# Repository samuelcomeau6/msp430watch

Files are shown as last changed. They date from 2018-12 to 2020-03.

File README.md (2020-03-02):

# msp430watch

These are the source and design files for my MSP430 based wrist watch.

See https://hackaday.io/project/163005-msp430fr5994-based-wrist-watch for project write up and documentation.

This project was designed for me to personally learn more about electronics design and embedded software design. As such, there are guaranteed to be bugs, issues and things that can be improved. I recommend not taking any of my instructions or designs at face value. However, I do have a working device so I must of done something right.

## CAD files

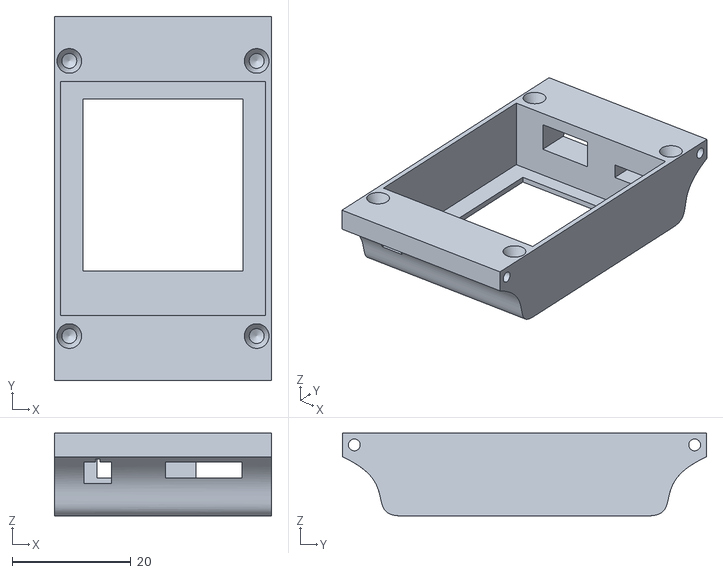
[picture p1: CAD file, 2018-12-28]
Case/body.stl
36.6 x 61.4 x 14.0

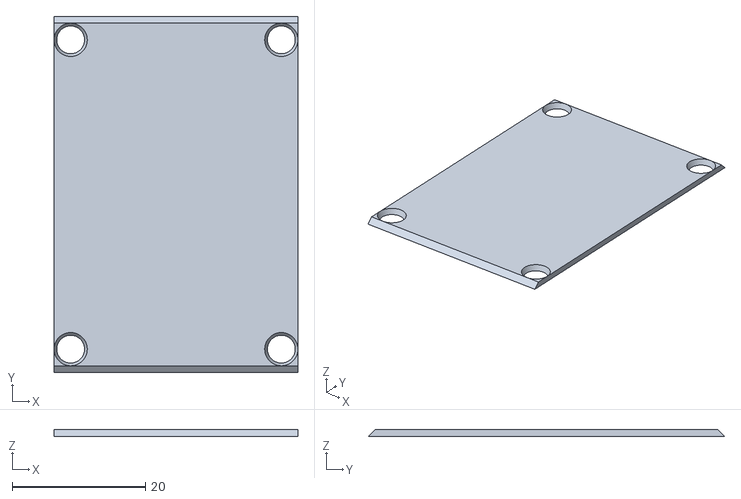
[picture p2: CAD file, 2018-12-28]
Case/backcover.stl
36.6 x 53.4 x 1.00

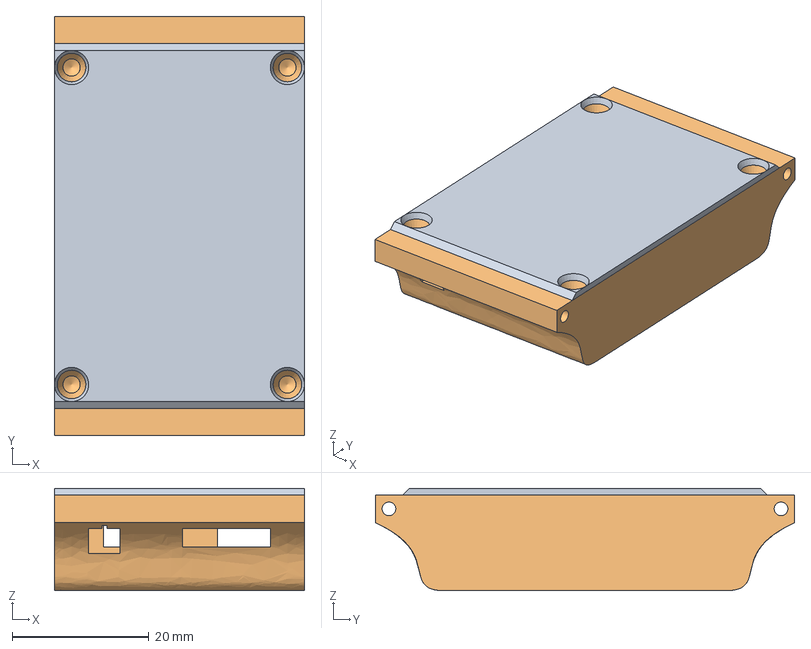
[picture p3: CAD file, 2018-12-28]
Case/watch body v4.step
36.6 x 61.4 x 15.0 mm

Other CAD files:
Case/watch body v4.f3d
Case/watch body v4.iges

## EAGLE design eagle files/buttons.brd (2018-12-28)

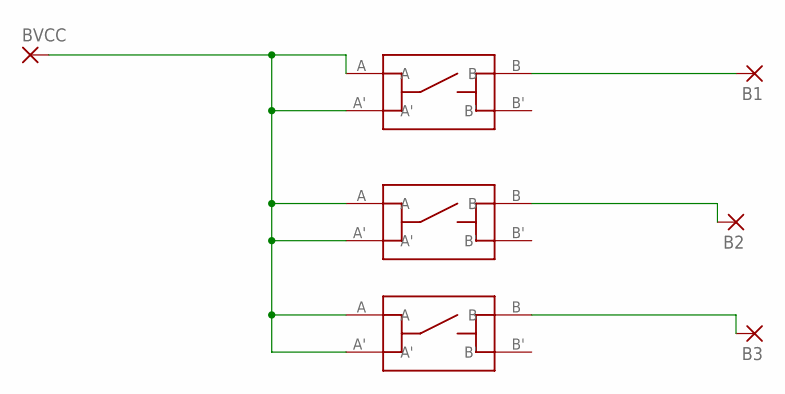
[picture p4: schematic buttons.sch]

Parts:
B1, B2, B3: 1,6/0,8
BVCC: 1,6/0,8
U$1, U$2, U$3: EVPBB; EVPVBB

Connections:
unnamed: BVCC.1, U$1.A, U$1.A', U$2.A, U$2.A', U$3.A, U$3.A'
unnamed: B1.1, U$1.B
unnamed: B3.1, U$3.B
unnamed: B2.1, U$2.B

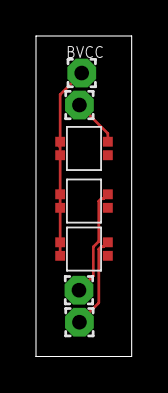
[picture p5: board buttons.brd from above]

Board: 2 copper layers, 5.3 x 17.8 mm, 7 parts (0 on the bottom side), 4 nets.

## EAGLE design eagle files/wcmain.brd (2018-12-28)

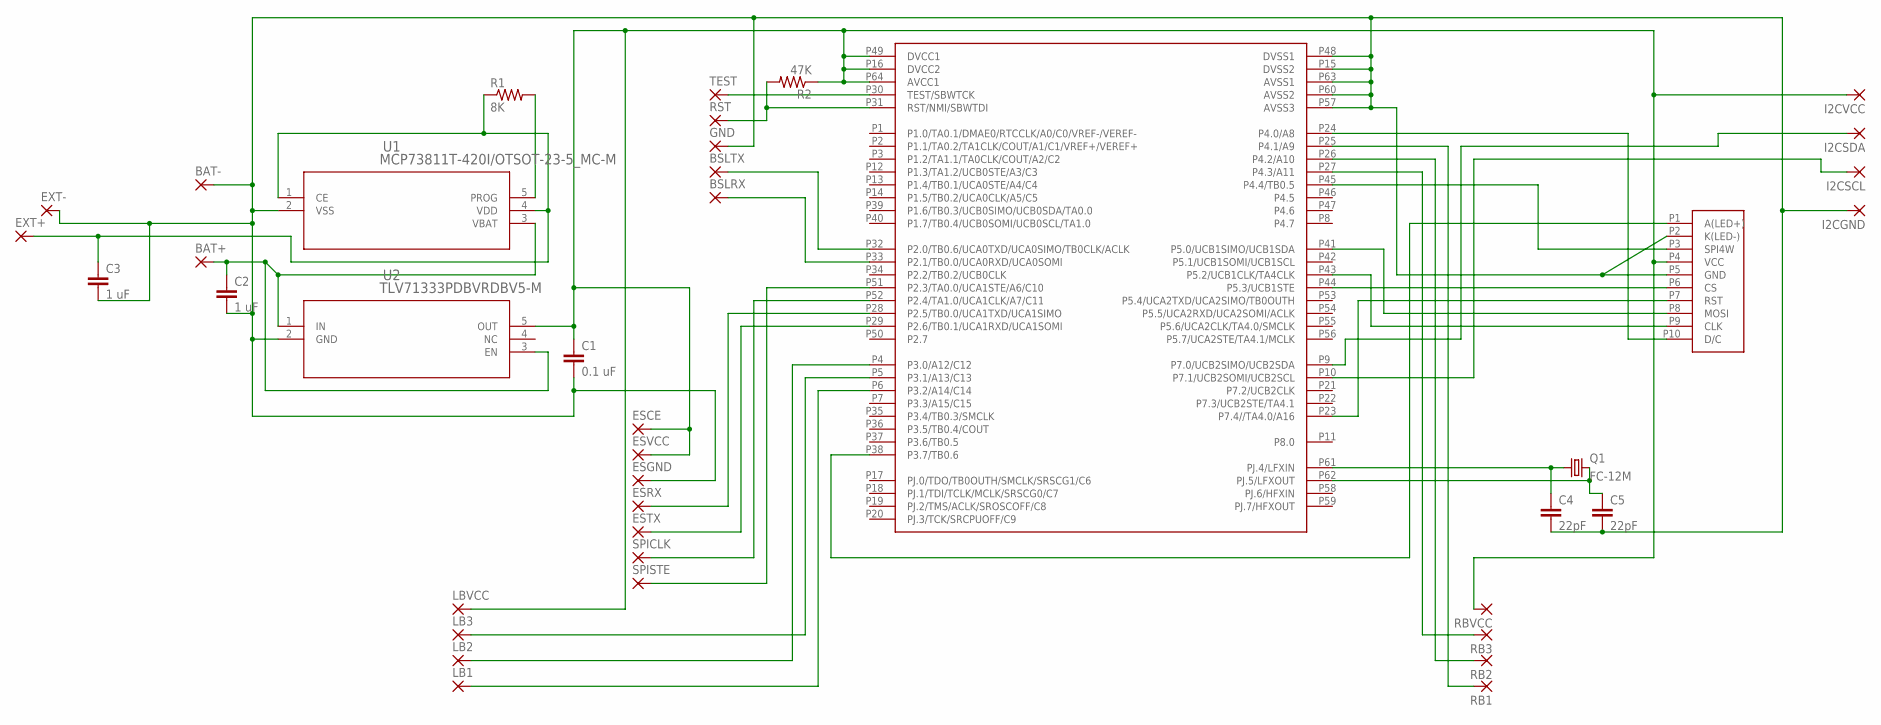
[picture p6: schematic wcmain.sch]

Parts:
BAT+: 1,6/0,8
BAT-: 1,6/0,8
BSLRX: 1,6/0,8
BSLTX: 1,6/0,8
C1: 0.1 uF; C0805
C2, C3: 1 uF; C0805
C4, C5: 22pF; C0805
ESCE: 1,6/0,8
ESGND: 1,6/0,8
ESRX: 1,6/0,8
ESTX: 1,6/0,8
ESVCC: 1,6/0,8
EXT+: 1,6/0,8
EXT-: 1,6/0,8
GND: 1,6/0,8
I2CGND, I2CSCL, I2CSDA, I2CVCC: 1,6/0,8
LB1, LB2, LB3: 1,6/0,8
LBVCC: 1,6/0,8
Q1: FC-12M
R1: 8K; R0402
R2: 47K; R0402
RB1, RB2, RB3: 1,6/0,8
RBVCC: 1,6/0,8
RST: 1,6/0,8
SPICLK: 1,6/0,8
SPISTE: 1,6/0,8
TEST: 1,6/0,8
U1: MCP73811T-420I/OTSOT-23-5_MC-M; SOT-23-5_MC-M
U2: TLV71333PDBVRDBV5-M; DBV5-M
U$1: MSP430FR5994PM; PM
U$2: 1-775333-0; 1-1775333-0

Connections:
EXT+: C3.1, EXT+.1, R1.1, U1.1 (CE), U1.4 (VDD)
GND: BAT-.1, C1.2, C2.2, C3.2, C4.2, C5.2, ESGND.1, EXT-.1, GND.1, I2CGND.1, U1.2 (VSS), U2.2 (GND), U$1.P15 (DVSS2), U$1.P48 (DVSS1), U$1.P57 (AVSS3), U$1.P60 (AVSS2), U$1.P63 (AVSS1), U$2.P2 (K(LED-)), U$2.P5 (GND)
unnamed: SPICLK.1, U$1.P52 (P2.4/TA1.0/UCA1CLK/A7/C11)
unnamed: R2.2, RST.1, U$1.P31 (RST/NMI/SBWTDI)
unnamed: SPISTE.1, U$1.P51 (P2.3/TA0.0/UCA1STE/A6/C10)
unnamed: U$1.P41 (P5.0/UCB1SIMO/UCB1SDA), U$2.P8 (MOSI)
unnamed: U$1.P43 (P5.2/UCB1CLK/TA4CLK), U$2.P9 (CLK)
unnamed: U$1.P24 (P4.0/A8), U$2.P10 (D/C)
unnamed: U$1.P23 (P7.4//TA4.0/A16), U$2.P7 (RST)
unnamed: U$1.P44 (P5.3/UCB1STE), U$2.P6 (CS)
unnamed: U$1.P38 (P3.7/TB0.6), U$2.P1 (A(LED+))
unnamed: U$1.P45 (P4.4/TB0.5), U$2.P3 (SPI4W)
unnamed: ESRX.1, U$1.P28 (P2.5/TB0.0/UCA1TXD/UCA1SIMO)
unnamed: TEST.1, U$1.P30 (TEST/SBWTCK)
unnamed: C4.1, Q1.1, U$1.P61 (PJ.4/LFXIN)
unnamed: R1.2, U1.5 (PROG)
unnamed: BSLTX.1, U$1.P32 (P2.0/TB0.6/UCA0TXD/UCA0SIMO/TB0CLK/ACLK)
unnamed: BSLRX.1, U$1.P33 (P2.1/TB0.0/UCA0RXD/UCA0SOMI)
unnamed: C5.1, Q1.2, U$1.P62 (PJ.5/LFXOUT)
unnamed: ESTX.1, U$1.P29 (P2.6/TB0.1/UCA1RXD/UCA1SOMI)
unnamed: LB2.1, U$1.P4 (P3.0/A12/C12)
unnamed: LB3.1, U$1.P5 (P3.1/A13/C13)
unnamed: LB1.1, U$1.P6 (P3.2/A14/C14)
unnamed: RB1.1, U$1.P25 (P4.1/A9)
unnamed: RB2.1, U$1.P26 (P4.2/A10)
unnamed: RB3.1, U$1.P27 (P4.3/A11)
unnamed: I2CSDA.1, U$1.P9 (P7.0/UCB2SIMO/UCB2SDA)
unnamed: I2CSCL.1, U$1.P10 (P7.1/UCB2SOMI/UCB2SCL)
VBAT: BAT+.1, C2.1, U1.3 (VBAT), U2.1 (IN), U2.3 (EN)
VCC: C1.1, ESCE.1, ESVCC.1, I2CVCC.1, LBVCC.1, R2.1, RBVCC.1, U2.5 (OUT), U$1.P16 (DVCC2), U$1.P49 (DVCC1), U$1.P64 (AVCC1), U$2.P4 (VCC)

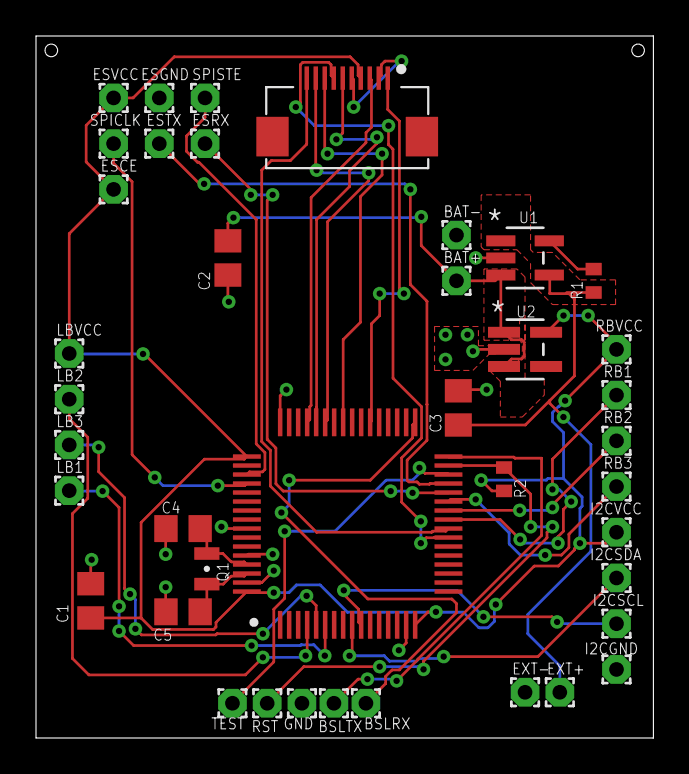
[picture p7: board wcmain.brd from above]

Board: 2 copper layers, 34.3 x 39.0 mm, 40 parts (0 on the bottom side), 30 nets.

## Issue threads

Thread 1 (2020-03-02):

Year resets to ~0600 when battery runs out

samuelcomeau6, 2020-03-02:
Year resets to 0600 (RTC default) when battery dies. This is very inconvenient. Instead, when in set mode, if year is <2000 then make year = 2000.

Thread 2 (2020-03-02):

Brightness Adjusts when turning on display

samuelcomeau6, 2020-03-02:
Since the brightness and display on buttons are the same, the brightness adjusts every time the display is turned on. Fix this by resetting button flags on state change.

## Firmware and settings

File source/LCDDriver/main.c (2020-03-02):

/*
 * main.c
 *
 *  Created on: Jan 19, 2018
 *      Author: samuel
 */

#include <msp430.h>

#include "ST7735.h"
#include "buttons.h"
#include "uart.h"
#include "clock.h"
#include "set.h"
#include "states.h"
#include "notes.h"
#include "sleep.h"

extern unsigned char buttons;
extern state_t state;
extern time_t NOW;


void IO_init(void);

void main(void) {
    //WDTCTL = WDTPW | WDTHOLD;
    WDTCTL = WDTPW | WDTSSEL_3 | WDTIS_3;               // Configure watchdog timer
    IO_init();
    LCD_init();
    uart_init();
    rtc_init();
    buttons_init();


    LCD_setbacklight(0x10);
    LCD_fill(0x00,0x00,0x00);  //Black
    LCD_text_color(0xFF,0xFF,0xFF); //White
    LCD_back_color(0x00,0x00,0x00); //Black
    state=CLOCK; //Clock
    //main loop:
    while(1){
        WDTCTL = WDTPW | WDTSSEL_3 | WDTIS_3 | WDTCNTCL;                  //Reset WDT
        switch(state){
        case OFF:
            //watch off
            state = off_mode();
            break;
        case TENS:
            //watch on 10s
            state = clock_mode(); //TODO implement on for 10s
            break;
        case CLOCK:
            state = clock_mode();
            break;
        case CMD:
            //CMD mode
            break;
        case SET:
            //Set Time
            state = set_mode(&NOW);
            break;
        case STOPW:
            //Stopwatch
            break;
        case TIMER:
            //Timer
            break;
        case NOTES:
            //Notes
            state = notes_mode();
            break;
        case DTCLOCK:
            //Dual Time
            state = clock_mode();//TODO DTMODE
            break;
        case CAL:
            //Calendar
            break;
        case CONS:
            //Console
            break;
        case ALARM:
            //Alarm
            break;
        default:
            state=CLOCK;
            break;
        }
        //Stop watchdog for power considerations
        WDTCTL = WDTPW | WDTSSEL_1 | WDTIS_3 | WDTHOLD;
        __bis_SR_register(LPM4_bits | GIE);
    }
}
void IO_init(void){
    //Set all unused pins to output
    P1DIR = 0xFF;
    P1OUT = 0x00;
    P2DIR = 0b10000100;
    P2OUT = 0x00;
    P3DIR = 0b01111000;
    P3OUT = 0x00;
    P4DIR = 0b11100000;
    P4OUT = 0x00;
    P5DIR = 0b11110010;
    P5OUT = 0x00;
    P6DIR = 0xFF; //Port doesn't exist?
    P6OUT = 0x00;
    P7DIR = 0b11101100;
    P7OUT = 0x00;
    P8DIR = 0xFF;
    P8OUT = 0x00;
    PJDIR = 0b11001111;
    PADIR = 0xFF;
    PAOUT = 0x00;
    PBDIR = 0xFF;
    PBOUT = 0x00;
    PCDIR = 0xFF;
    PCOUT = 0x00;
    PDDIR = 0xFF;
    PDOUT = 0x00;
}

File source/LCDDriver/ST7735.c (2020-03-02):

/*
 * ST7735.c
 *
 *  Created on: Jan 19, 2018
 *      Author: samuel
 */
#include <ST7735.h>
#include <msp430.h>
#include <fifo.h>
#include <stdarg.h>
#include <stdio.h>

#define SET(x) |= x
#define CLR(x) &= ~x
#define DC BIT0 //Bit 0
#define RST BIT4 //Bit 4
char data=0x00;
_Bool cmd=1;
int empty=1;
unsigned char RXData;
unsigned char TXData;
unsigned char textR,textG,textB;
unsigned char backR,backG,backB;
unsigned char brightness;
void LCD_init(){
    //Initialize Fifo
    TxFifo_Init();
    //Port definitions
    //4.0 D/C
    P4SEL0 CLR(DC);
    P4SEL1 CLR(DC);
    P4DIR SET(DC);
    P4OUT SET(DC);
    //3.7 Backlight (TB0.6)
    P3DIR SET(BIT7);
    P3SEL0 SET(BIT7);
    P3SEL1 CLR(BIT7);
    TB0CTL SET(CNTL_3);
    TB0CTL SET(TBSSEL__ACLK); //TB0 @ 3.27khz
    TB0CTL SET(MC_2); //Set continuous mode
    TB0CCR0 = 255;
    TB0CCR6 = 0xEF;
    TB0CCTL6 = OUTMOD_7;
    //7.4 Reset
    P7SEL0 CLR(RST);
    P7SEL1 CLR(RST);
    P7DIR SET(RST);
    P7OUT SET(RST);
    //4.4 SPI4W
    P4SEL0 CLR(BIT4);
    P4SEL1 CLR(BIT4);
    P4DIR SET(BIT4);
    P4OUT SET(BIT4);
    //===SPI Initialization====
    P5DIR |= BIT0|BIT1|BIT2|BIT3;
    P5SEL0 SET(BIT0); //Pin 5.0=UCB1SIMO (MOSI)
    P5SEL0 SET(BIT1); //Pin 5.1=UCB1SOMI (MISO)
    P5SEL0 SET(BIT2); //Pin 5.2=UCB1CLK  (CLK)
    P5SEL0 SET(BIT3); //Pin 5.3=UCB1STE  (CS)

    //Set clocks
    FRCTL0 = FRCTLPW;
    FRCTL0_L |= NWAITS_1_L;
    CSCTL0_H = CSKEY_H; // Unlock clock system
    CSCTL1 CLR(DCOFSEL0); // Set digital controlled oscillator to 24MHz!
    CSCTL1 SET(DCOFSEL1);
    CSCTL1 SET(DCOFSEL2);
    CSCTL1 SET(DCORSEL); // Range select is 0
    CSCTL2 = SELA__LFXTCLK | SELS__DCOCLK | SELM__DCOCLK; //ACLK from 3.27kHz external, Sclk+Mclk from DCO
    CSCTL3 = DIVA__1 | DIVS__1 | DIVM__1;   // Set all dividers
    CSCTL4 CLR(LFXTOFF);  //Turn on LFXT
    CSCTL4 CLR(SMCLKOFF); //Make sure SMCLK is on

    //Setup UCB1
    UCB1CTLW0 = UCSWRST; //Reset module
    UCB1CTLW0 SET(UCCKPH);  //set clock phase?
    UCB1CTLW0 CLR(UCCKPL); //Inactive low CLK
    UCB1CTLW0 SET(UCMSB); //MSB first
    UCB1CTLW0 CLR(UC7BIT); //8-bit
    UCB1CTLW0 SET(UCMST); //Set Master
    UCB1CTLW0 SET(UCMODE1); //Set 4-pin SPI STE(CS) active low
    UCB1CTLW0 SET(UCSYNC); //Has to be set to enable SPI
    UCB1CTLW0 SET(UCSSEL__SMCLK); //Clock source SCLK
    UCB1CTLW0 SET(UCSTEM); //4-wire SPI
    UCB1BRW = 0x0000; //Set bit rate SMCLK MHz

    UCB1CTLW0 CLR(UCSWRST); //Start SPI module
    UCB1IE SET(UCTXIE);

    PM5CTL0 &= ~LOCKLPM5;
    //Reset
    P7OUT CLR(RST);
    //Wait 1ms
    __delay_cycles(1000);
    //High Reset pin
    P7OUT SET(RST);
    //Wait 150ms
    __delay_cycles(150000);
    //SLPOUT
    LCD_cmd(SLPOUT);
    //Wait 120ms
    __delay_cycles(120000);
    //Set frame control 1 TODO optimize frame rate
    LCD_cmd(FRMCTR1); //framerate In normal mode FR=850K/((RTNA x 2 + 40) x (LINE + FPA + BPA +2)) =>Min=45FPS
    LCD_data(0x0F);//RTNA=16
    LCD_data(0x40);//FPA=64
    LCD_data(0x40);//BPA=54
    //Set display inversion
    LCD_cmd(INVCTR);
    LCD_data(0x07);
    //Set power control 1 to 4.70v 2.5uA
    LCD_cmd(PWCTR1);
    LCD_data(0x02);// VRHP[4:0] (0-31) Sets GVDD=4.6V
    LCD_data(0x02);// VRHN[4:0] Set GVCL=-4.6
    //Set power control 2 to -7.35v
    LCD_cmd(PWCTR2);
    LCD_data(0xC5);// VGHBT[1:0] (0-15) Sets VGH=3*AVDD+VGH25-0.5 VGL=-7.5 VGH=2.4
    //Set power control 3 to large, booster freq = BCLK
    LCD_cmd(PWCTR3);
    LCD_data(0x0D);// AP[2:0] Sets Operational Amplifier Bias Current
    LCD_data(0x00);// DC[2:0] Booster Frequency
    //Set power control 4 to large, BCLK/4
    LCD_cmd(PWCTR4);
    LCD_data(0x8D);// AP[2:0] Sets Operational Amplifier Bias Current
    LCD_data(0x1A);// DC[2:0] Booster Frequency
    //set pc 5
    LCD_cmd(PWCTR5);
    LCD_data(0x8D);// AP[2:0] Sets Operational Amplifier Bias Current
    LCD_data(0xEE);// DC[2:0] Booster Frequency
    //Set vcom ctrl 1
    LCD_cmd(VMCTR1);
    LCD_data(0x51);// Default: 0x51 => +4.525
    LCD_data(0x4D);// Default: 0x4D => -0.575
    //Set gamma CTRP1
    LCD_cmd(GAMCTRP1);
    LCD_data(0x0a);
    LCD_data(0x1c);
    LCD_data(0x0c);
    LCD_data(0x14);
    LCD_data(0x33);
    LCD_data(0x2b);
    LCD_data(0x24);
    LCD_data(0x28);
    LCD_data(0x27);
    LCD_data(0x25);
    LCD_data(0x2C);
    LCD_data(0x39);
    LCD_data(0x00);
    LCD_data(0x05);
    LCD_data(0x03);
    LCD_data(0x0d);
    //Set GAMCTRN1
    LCD_cmd(GAMCTRN1);
    LCD_data(0x0a);
    LCD_data(0x1c);
    LCD_data(0x0c);
    LCD_data(0x14);
    LCD_data(0x33);
    LCD_data(0x2b);
    LCD_data(0x24);
    LCD_data(0x28);
    LCD_data(0x27);
    LCD_data(0x25);
    LCD_data(0x2D);
    LCD_data(0x3a);
    LCD_data(0x00);
    LCD_data(0x05);
    LCD_data(0x03);
    LCD_data(0x0d);

    //Set pixel format to 18b
    LCD_cmd(COLMOD);
    LCD_data(0x06);// Default: 0x06 => 18-bit/pixel
    //Display on
    LCD_cmd(DISPON);//Display On
    LCD_cmd(IDMOFF);
    //wait 1 ms
    __delay_cycles(1000);
    //Set MADCTL
    LCD_cmd(MADCTL);
    LCD_data(0b10000100);//Set MY=1 MX=0 MV=0 ML=0 RGB=0 MH=0

}
void LCD_cmd(unsigned char byte){
    TxFifo_Put(byte,1);
    UCB1IFG SET(UCTXIFG);
    __bis_SR_register(GIE);

}
void LCD_data(unsigned char byte){
    TxFifo_Put(byte,0);
    UCB1IFG SET(UCTXIFG);
    __bis_SR_register(GIE);
}

void LCD_setbacklight(unsigned char byte){
    brightness = byte;
    TB0CCR6=brightness;
}
unsigned char LCD_adjustbacklight(signed char delta){
    brightness+=delta;
    TB0CCR6=brightness;
    return brightness;
}
void LCD_on(void){
    LCD_cmd(DISPON);
    TB0CCTL6 = OUTMOD_7;
    TB0CCR6=brightness;
    TB0CTL SET(MC_2);
}
void LCD_off(void){
    TB0CTL=TB0CTL&~0x0030;
    TB0CCTL6 = OUTMOD_0;
    LCD_cmd(DISPOFF);

}
void LCD_coord(unsigned char x, unsigned char y){
    LCD_cmd(CASET);
    LCD_data(0x00);
    LCD_data(x);//XS
    LCD_data(0x00);
    LCD_data(MAXX);//XE

    LCD_cmd(RASET);
    LCD_data(0x00);
    LCD_data(y);//YS
    LCD_data(0x00);
    LCD_data(MAXY);//YE

    LCD_cmd(RAMWR);
}
void LCD_window(unsigned char x, unsigned char y,unsigned char x2, unsigned char y2){
    LCD_cmd(CASET);
    LCD_data(0x00);
    LCD_data(x);//XS
    LCD_data(0x00);
    LCD_data(x2);//XE

    LCD_cmd(RASET);
    LCD_data(0x00);
    LCD_data(y);//YS
    LCD_data(0x00);
    LCD_data(y2);//YE

    LCD_cmd(RAMWR);
}
void LCD_line(int x0, int y0, int x1, int y1) {
    //Bitmap/Bresenham's line algorithm <http://rosettacode.org/wiki/Bitmap/Bresenham%27s_line_algorithm#C>
    int dx = abs(x1-x0), sx = x0<x1 ? 1 : -1;
    int dy = abs(y1-y0), sy = y0<y1 ? 1 : -1;
    int err = (dx>dy ? dx : -dy)>>1, e2;

    for(;;){
        LCD_pixel(x0,y0,textR,textG,textB);
        if (x0==x1 && y0==y1) break;
        e2 = err;
        if (e2 >-dx) { err -= dy; x0 += sx; }
        if (e2 < dy) { err += dx; y0 += sy; }
    }
}
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

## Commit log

2018-12-28 Added all the files
    [ST7735.obj, backcover.stl, body.stl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]
2020-03-02 Updated Remote to Local
    [ST7735.obj, fifo.obj, main.obj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]
